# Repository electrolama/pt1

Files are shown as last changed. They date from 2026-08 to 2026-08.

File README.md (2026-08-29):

# pt1

pt1 brings several common hardware-debugging functions together on a compact
USB-connected board. It provides extra USB ports, a serial interface, and
software-switchable power for working with target devices.

For an overview, documentation, and usage information, see the
[pt1 project documentation](https://lab.electrolama.com/project/pt1).

## Companion software

[Vicuña](https://lab.electrolama.com/project/vicuna) is Electrolama's
browser-based serial monitor and terminal, with a dedicated pt1 mode for power
control and fault monitoring.

## License

**Hardware source**, including schematics, PCB design files, mechanical CAD, manufacturing files, 
and other source material required to make or modify the hardware, is licensed under the
[**CERN Open Hardware Licence Version 2 — Weakly Reciprocal**](LICENSES/CERN-OHL-W-2.0.txt)
(CERN-OHL-W-2.0).

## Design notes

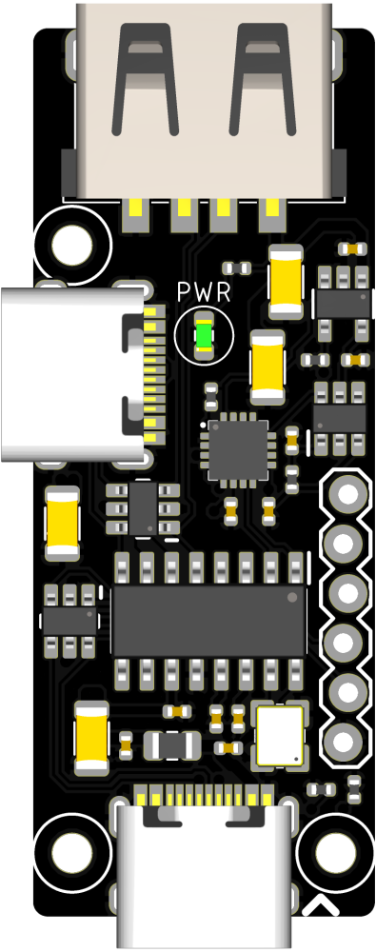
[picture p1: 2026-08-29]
pinout/board.png

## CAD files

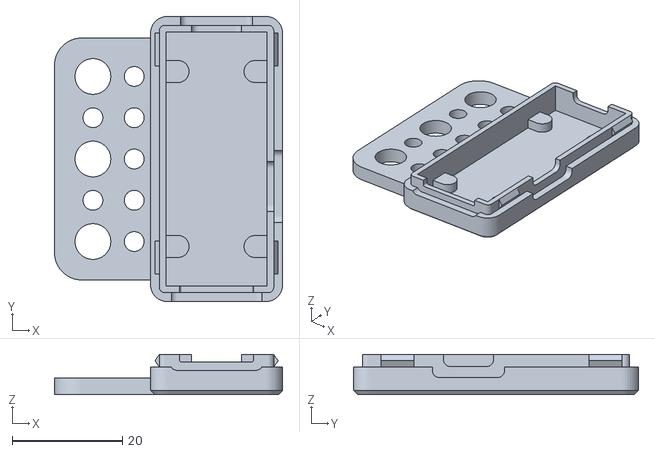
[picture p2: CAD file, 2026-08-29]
case/Rev A/pt1_case_bottom_oobb_RevA.stl
41.5 x 51.8 x 7.30

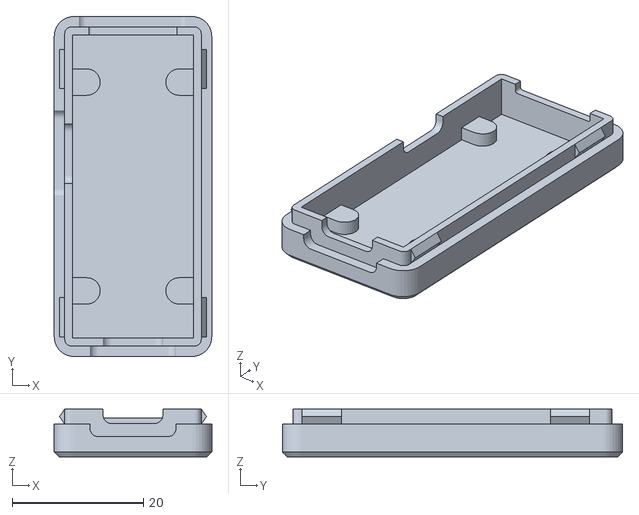
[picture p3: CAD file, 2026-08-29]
case/Rev A/pt1_case_bottom_RevA.stl
24.0 x 51.8 x 7.30

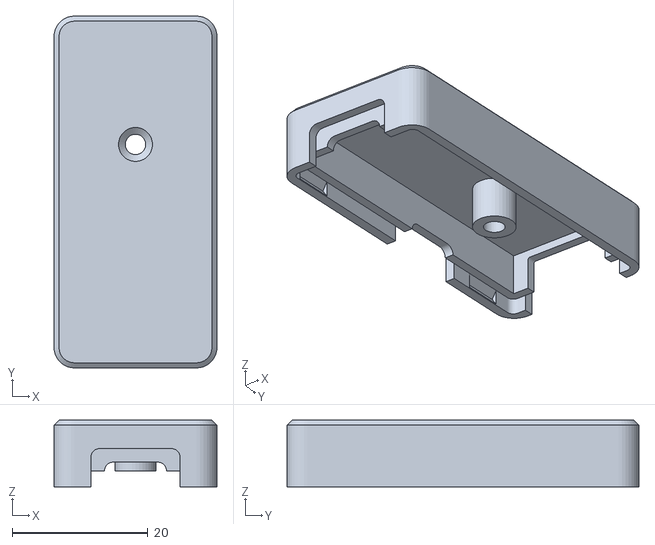
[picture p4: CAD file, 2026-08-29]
case/Rev A/pt1_case_top_noHeader_RevA.stl
24.0 x 51.8 x 9.85

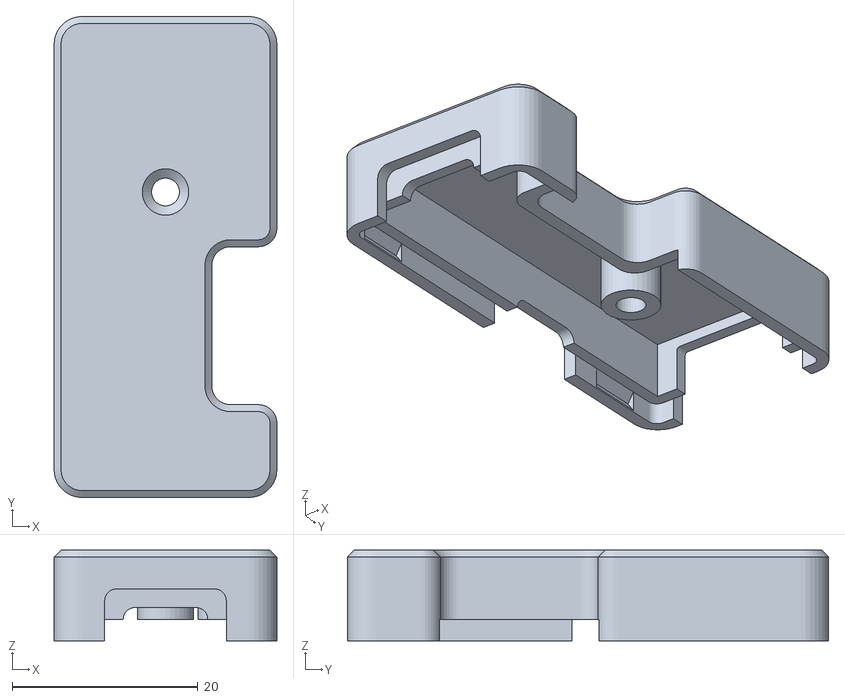
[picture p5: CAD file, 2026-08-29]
case/Rev A/pt1_case_top_withHeader_RevA.stl
24.0 x 51.8 x 9.80

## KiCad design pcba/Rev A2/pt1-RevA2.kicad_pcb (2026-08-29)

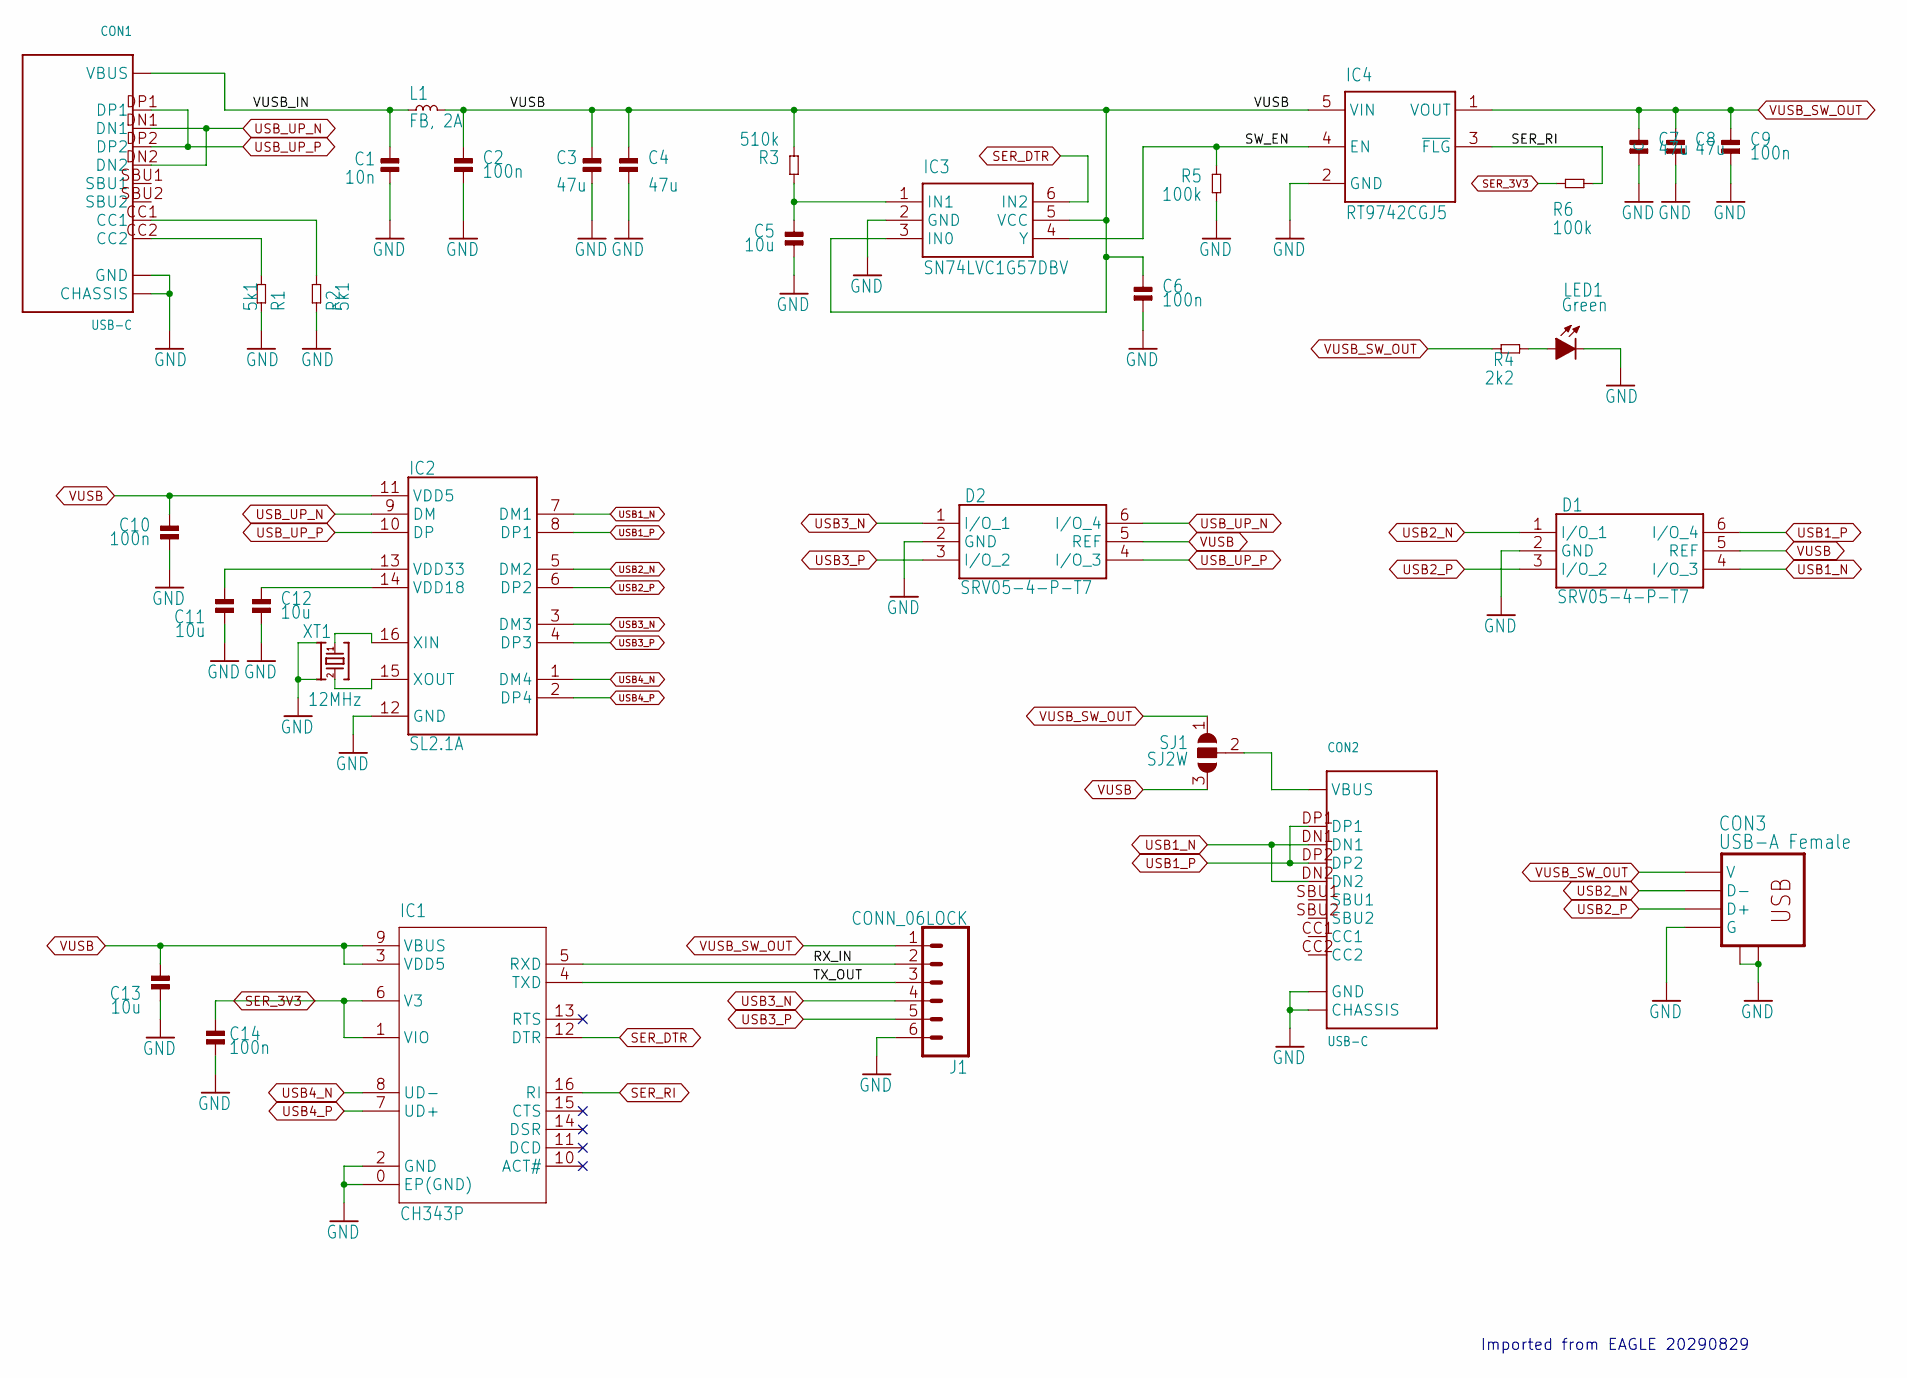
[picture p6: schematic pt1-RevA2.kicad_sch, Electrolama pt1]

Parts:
C1: 10n; _PKG_C_0402; MPN CL05B103KB5NNNC; JLCASSY C15195
C2, C6, C9, C10, C14: 100n; _PKG_C_0402; MPN CL05B104KO5NNNC; JLCASSY C1525
C3, C4, C7, C8: 47u; _PKG_C_1206; MPN CL31A476MPHNNNE; JLCASSY C96123
C5, C11, C12, C13: 10u; _PKG_C_0402; MPN CL05A106MQ5NUNC; JLCASSY C15525
CON1, CON2: USB-C; USBC_C-31-M-12; MPN TYPE-C-31-M-12; JLCASSY C165948
CON3: USB-A Female; JING_912-121A2023S10100; MPN 912-121A2023S10100; JLCASSY C42428
D1, D2: SRV05-4-P-T7; SOT95P280X145-6N; MANUFACTURER_PART_NUMBER SRV05-4-P-T7; JLCASSY C85364
IC1: CH343P; QFN16_L3.0-W3.0-P0.50-EP1.7; MPN CH343P; JLCASSY C2846043
IC2: SL2.1A; SOIC127P604X185-16N; MANUFACTURER_PART_NUMBER SL2.1A; JLCASSY C192893
IC3: SN74LVC1G57DBV; SOT95P280X145-6N; MANUFACTURER_PART_NUMBER SN74LVC1G57DBVRG4; MOUSER_PART_NUMBER 595-74LVC1G57DBVRG4
IC4: RT9742CGJ5; _PKG_SOT23-5; MPN RT9742CGJ5; JLCASSY C250546
J1: CONN_06LOCK; 1X06_LOCK
L1: FB, 2A; _PKG_C_0805; MPN BLM21PG221SN1D; JLCASSY C85840
LED1: Green; _PKG_LED_0603; MPN 19-217/GHC-YR1S2/3T; JLCASSY C72043
R1, R2: 5k1; _PKG_R_0402; MPN AC0402FR-075K1L; JLCASSY C144745
R3: 510k; _PKG_R_0402; MPN 0402WGF5103TCE; JLCASSY C11616
R4: 2k2; _PKG_R_0402; MPN 0402WGF2201TCE; JLCASSY C25879
R5, R6: 100k; _PKG_R_0402; MPN 0402WGF1003TCE; JLCASSY C25741
SJ1: SJ2W; SJ_2
XT1: 12MHz; XTAL-4P-3225; MPN X322512MSB4SI; JLCASSY C9002

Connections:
GND: C1.1, C2.1, C3.2, C4.2, C5.1, C6.1, C7.1, C8.1, C9.1, C10.1, C11.1, C12.1, C13.1, C14.1, CON1.GND@1 (GND), CON1.GND@2 (GND), CON1.P$1 (CHASSIS), CON1.P$2 (CHASSIS), CON1.P$3 (CHASSIS), CON1.P$4 (CHASSIS), CON1.P$5 (CHASSIS), CON1.P$6 (CHASSIS), CON1.P$7 (CHASSIS), CON1.P$8 (CHASSIS), CON2.GND@1 (GND), CON2.GND@2 (GND), CON2.P$1 (CHASSIS), CON2.P$2 (CHASSIS), CON2.P$3 (CHASSIS), CON2.P$4 (CHASSIS), CON2.P$5 (CHASSIS), CON2.P$6 (CHASSIS), CON2.P$7 (CHASSIS), CON2.P$8 (CHASSIS), CON3.GND (G), CON3.P$5 (SHIELD1), CON3.P$6 (SHIELD2), D1.2 (GND), D2.2 (GND), IC1.0 (EP(GND)), IC1.2 (GND), IC2.12 (GND), IC3.2 (GND), IC4.2 (GND), J1.6, LED1.C, R1.1, R2.1, R5.2, XT1.2, XT1.4
unnamed: IC2.16 (XIN), XT1.1
unnamed: CON2.VBUS@1 (VBUS), CON2.VBUS@2 (VBUS), SJ1.2
unnamed: LED1.A, R4.1
unnamed: IC2.15 (XOUT), XT1.3
unnamed: C5.2, IC3.1 (IN1), R3.2
unnamed: CON1.CC1, R2.2
unnamed: CON1.CC2, R1.2
unnamed: C11.2, IC2.13 (VDD33)
unnamed: C12.2, IC2.14 (VDD18)
RX_IN: IC1.5 (RXD), J1.2
SER_3V3: C14.2, IC1.1 (VIO), IC1.6 (V3), R6.1
SER_DTR: IC1.12 (DTR), IC3.6 (IN2)
SER_RI: IC1.16 (RI), IC4.3 (~FLG), R6.2
SW_EN: IC3.4 (Y), IC4.4 (EN), R5.1
TX_OUT: IC1.4 (TXD), J1.3
USB1_N: CON2.DN1, CON2.DN2, D1.4 (I/O_3), IC2.7 (DM1)
USB1_P: CON2.DP1, CON2.DP2, D1.6 (I/O_4), IC2.8 (DP1)
USB2_N: CON3.DM (D-), D1.1 (I/O_1), IC2.5 (DM2)
USB2_P: CON3.DP (D+), D1.3 (I/O_2), IC2.6 (DP2)
USB3_N: D2.1 (I/O_1), IC2.3 (DM3), J1.4
USB3_P: D2.3 (I/O_2), IC2.4 (DP3), J1.5
USB4_N: IC1.8 (UD-), IC2.1 (DM4)
USB4_P: IC1.7 (UD+), IC2.2 (DP4)
USB_UP_N: CON1.DN1, CON1.DN2, D2.6 (I/O_4), IC2.9 (DM)
USB_UP_P: CON1.DP1, CON1.DP2, D2.4 (I/O_3), IC2.10 (DP)
VUSB: C2.2, C3.1, C4.1, C6.2, C10.2, C13.2, D1.5 (REF), D2.5 (REF), IC1.3 (VDD5), IC1.9 (VBUS), IC2.11 (VDD5), IC3.3 (IN0), IC3.5 (VCC), IC4.5 (VIN), L1.2, R3.1, SJ1.3
VUSB_IN: C1.2, CON1.VBUS@1 (VBUS), CON1.VBUS@2 (VBUS), L1.1
VUSB_SW_OUT: C7.2, C8.2, C9.2, CON3.VBUS (V), IC4.1 (VOUT), J1.1, R4.2, SJ1.1

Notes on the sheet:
Imported from EAGLE 20290829

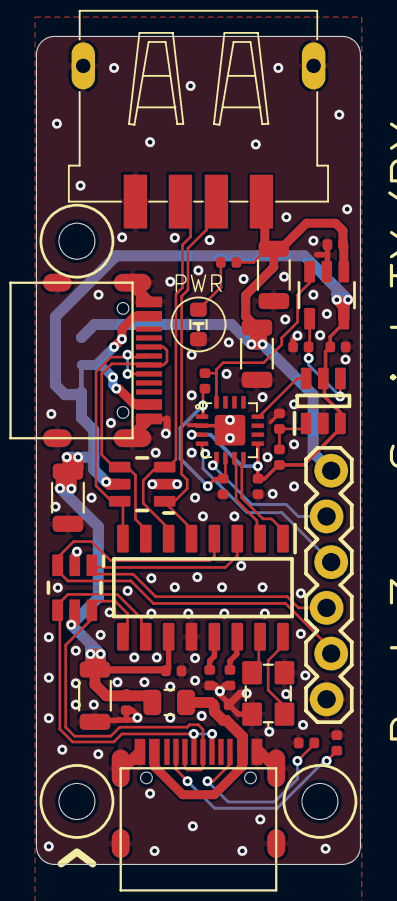
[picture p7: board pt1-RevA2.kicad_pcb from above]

Board: 2 copper layers, 18.0 x 46.0 mm, 37 parts (1 on the bottom side), 29 nets.

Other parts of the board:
UNK_HOLE_0: dummyfp0
UNK_HOLE_1: dummyfp1
UNK_HOLE_2: dummyfp2

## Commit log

2026-08-29 add case revision A
    [pt1_case_bottom_RevA.stl, pt1_case_top_noHeader_RevA.stl, pt1_case_top_withHeader_RevA.stl]
2026-08-29 initial import for pcba Rev A2
    [pt1-RevA2.kicad_pcb, pt1-RevA2.kicad_sch]
